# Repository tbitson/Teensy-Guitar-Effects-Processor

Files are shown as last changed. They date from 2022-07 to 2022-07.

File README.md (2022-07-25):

Teensy Guitar Effects Processor

This is an in-work project!

The Teensy Guitar Effects Processor (Teensy GEP or just GEP) is a microcontroller based sound effects processor designed for enhancing and modifying electric guitar sounds. It uses a Teensy microcontroller paired with a dedicated sound processing chip to provide a multitude of effects. 

The base design uses a Teensy 3.2 along with the Teensy Audio Shield from PJRC (pjrc.com) to process stereo audio at a full 16-bit 44.1kHz sample rate. The audio shield supports line-level-in, line-level out, and has an on-board headphone jack. The shield also contain a micro-SD card slot to allow recording and playback of sound. A separate battery powered pre-amp module interfaces most common electric guitar pickups to the line-level input. 

The design inspiration for the Teensy GEP is based on a project that appeared in the July 2017 edition of Circuit Cellar magazine by Brian Miller.  The original version of the source code (dubbed 1.0) does not seem to have any significant change since the article was published, and no longer compiles with the current version of the Teensy compiler and/or audio libraries. Significant changes to the baseline code were required to a) bring up-to-date with current library versions, 2) match the current compiler versions, and 3) to simplify the code so that my limited brain power could understand how the code worked (or at least how I thought I worked). 

Starting with Version 1.4, the memory requirements exceeded the Teensy 3.2, and either a Teensy 3.5 or 3.6 must be used. The devices are pin-for-pin compatable, however the 3.5 and 3.6 are both physically long with additional pins. A re-spin of the PC board will include the new footprint. This project is NOT electrically compatible with Teensy 4.0, but the software is. Change the #define in hardware.h to select your device.

The next milestone is to create a class hierarchy for the effects to allow easy implementation of new effects and/or changes to existing effects.

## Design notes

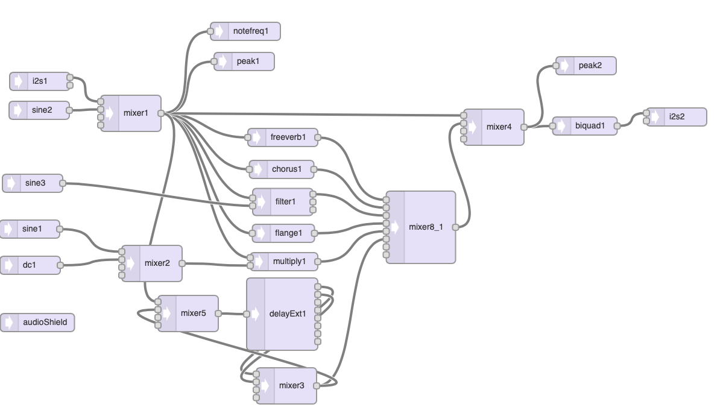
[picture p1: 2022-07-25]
Vers 185 Patches.png

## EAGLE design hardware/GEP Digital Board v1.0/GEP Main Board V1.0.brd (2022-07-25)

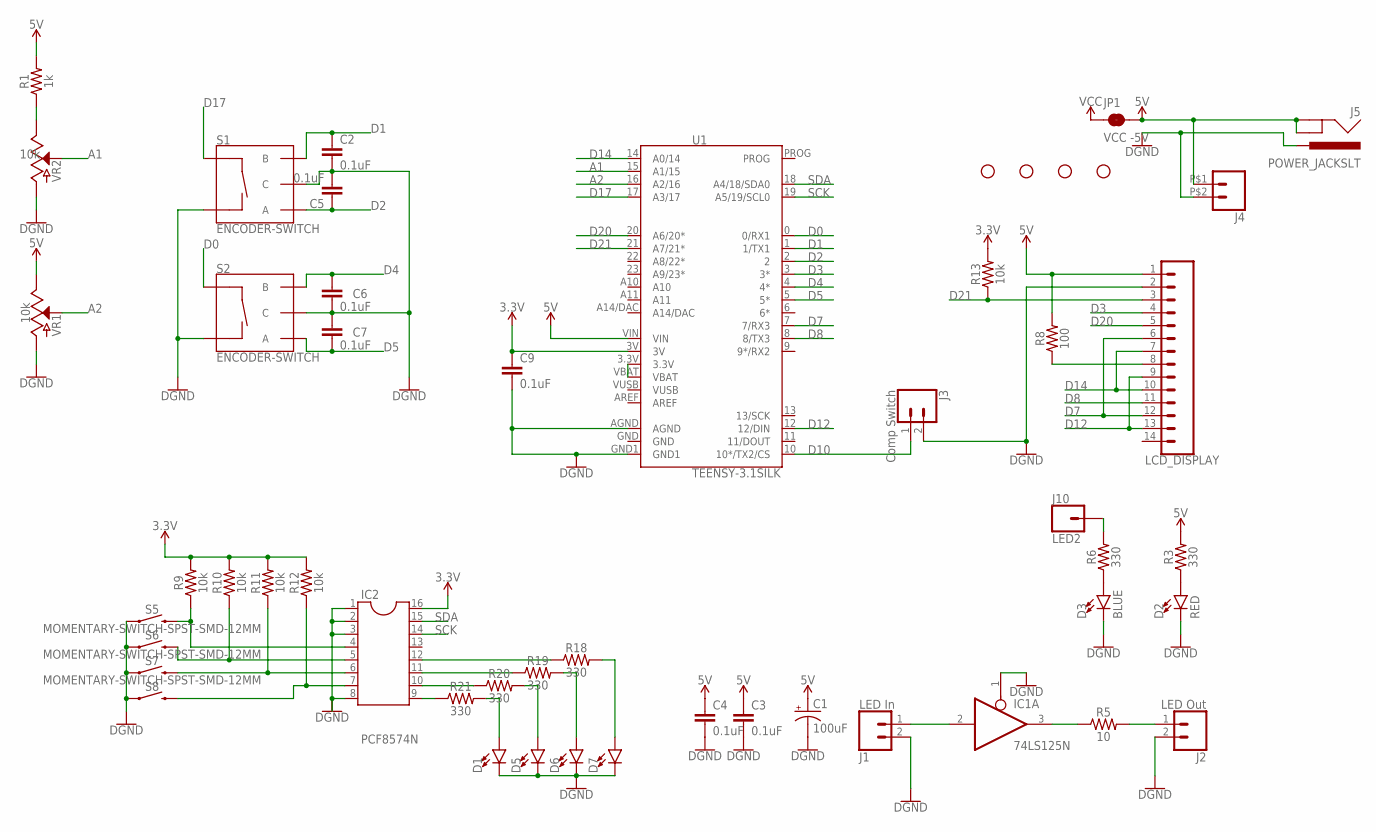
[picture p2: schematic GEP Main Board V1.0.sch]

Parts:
C1: 100uF; CPOL-RADIAL-2.5MM-6.5MM
C2, C3, C4, C5, C6, C7, C9: 0.1uF; CAP-PTH-SMALL-KIT
D1, D5, D6, D7: LED5MM; LED_5MM
D2: RED; LED_5MM
D3: BLUE; LED_5MM
H1, H2, H3, H4: STAND-OFF
IC1: 74LS125N; DIL14
IC2: PCF8574N; SOCKET-16
J1: LED In; 1X02
J2: LED Out; 1X02
J3: Comp Switch; 1X02
J4: CONN_02PTH2; 1X02_BIG
J5: POWER_JACKSLT; POWER_JACK_SLOT
J10: LED2; 1X01
JP1: VCC -5V; SMT-JUMPER_2_NC_TRACE_SILK
LCDDISPLAY: LCD_DISPLAY; 1X14
R1: 1k; AXIAL-0.3
R3, R6, R18, R19, R20, R21: 330; AXIAL-0.3
R5: 10; AXIAL-0.3
R8: 100; AXIAL-0.3
R9, R10, R11, R12, R13: 10k; AXIAL-0.3
S1, S2: ENCODER-SWITCH; ROTARY_ENC_PLAIN
S5, S6, S7, S8: MOMENTARY-SWITCH-SPST-SMD-12MM; TACTILE_SWITCH_SMD_12MM
U1: TEENSY-3.1SILK; TEENSY-3.1
VR1, VR2: 10k; POT-PTH-ALPS-KIT

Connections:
3.3V: C9.1, IC2.16, R9.P$2 (2), R10.P$2 (2), R11.P$2 (2), R12.P$2 (2), R13.P$2 (2), U1.3V
5V: C1.1 (+), C3.1, C4.1, J4.P$1 (1), J5.GND@1 (GNDBREAK), J5.GND@2 (GND), JP1.2, LCDDISPLAY.1, R1.P$2 (2), R3.P$2 (2), R8.P$2 (2), U1.VIN, VR1.P$1 (E)
A1: U1.15 (A1/15), VR2.P$2 (S)
A2: U1.16 (A2/16), VR1.P$2 (S)
D0: S2.SW+, U1.0 (0/RX1)
D1: C2.1, S1.B, U1.1 (1/TX1)
D2: C5.1, S1.A, U1.2
D3: LCDDISPLAY.4, U1.3 (3*)
D4: C6.1, S2.B, U1.4 (4*)
D5: C7.2, S2.A, U1.5 (5*)
D7: LCDDISPLAY.6, LCDDISPLAY.12, U1.7 (7/RX3)
D8: LCDDISPLAY.11, U1.8 (8/TX3)
D10: J3.1, U1.10 (10*/TX2/CS)
D12: LCDDISPLAY.9, LCDDISPLAY.13, U1.12 (12/DIN)
D14: LCDDISPLAY.7, LCDDISPLAY.10, U1.14 (A0/14)
D17: S1.SW+, U1.17 (A3/17)
D20: LCDDISPLAY.5, U1.20 (A6/20*)
D21: LCDDISPLAY.3, R13.P$1 (1), U1.21 (A7/21*)
GND: C1.2 (-), C2.2, C3.2, C4.2, C5.2, C6.2, C7.1, C9.2, D1.K (C), D2.K (C), D3.K (C), D5.K (C), D6.K (C), D7.K (C), IC1.1 (OE), IC1.7 (GND), IC2.1, IC2.2, IC2.3, IC2.8, J1.2, J2.2, J3.2, J4.P$2 (2), J5.PWR, LCDDISPLAY.2, S1.C, S1.SW-, S2.C, S2.SW-, S5.1, S6.1, S7.1, S8.1, U1.AGND, U1.GND, U1.GND1, VR1.P$3 (A), VR2.P$3 (A)
LED: LCDDISPLAY.8, R8.P$1 (1)
unnamed: U1.3.3V, U1.VBAT
unnamed: IC2.9, R21.P$1 (1)
unnamed: IC2.10, R20.P$1 (1)
unnamed: IC1.2 (I), J1.1
unnamed: IC1.3 (O), R5.P$1 (1)
unnamed: R1.P$1 (1), VR2.P$1 (E)
unnamed: D3.A, R6.P$1 (1)
unnamed: D2.A, R3.P$1 (1)
unnamed: IC2.5, R10.P$1 (1), S6.3 (2)
unnamed: IC2.6, R11.P$1 (1), S7.3 (2)
unnamed: IC2.7, R12.P$1 (1), S8.3 (2)
unnamed: IC2.4, R9.P$1 (1), S5.3 (2)
unnamed: J2.1, R5.P$2 (2)
unnamed: IC2.11, R19.P$1 (1)
unnamed: IC2.12, R18.P$1 (1)
unnamed: D1.A, R21.P$2 (2)
unnamed: D5.A, R20.P$2 (2)
unnamed: D6.A, R19.P$2 (2)
unnamed: D7.A, R18.P$2 (2)
unnamed: J10.1, R6.P$2 (2)
SCK: IC2.14, U1.19 (A5/19/SCL0)
SDA: IC2.15, U1.18 (A4/18/SDA0)
VCC: IC1.14 (VCC), JP1.1
VUSB: U1.VUSB

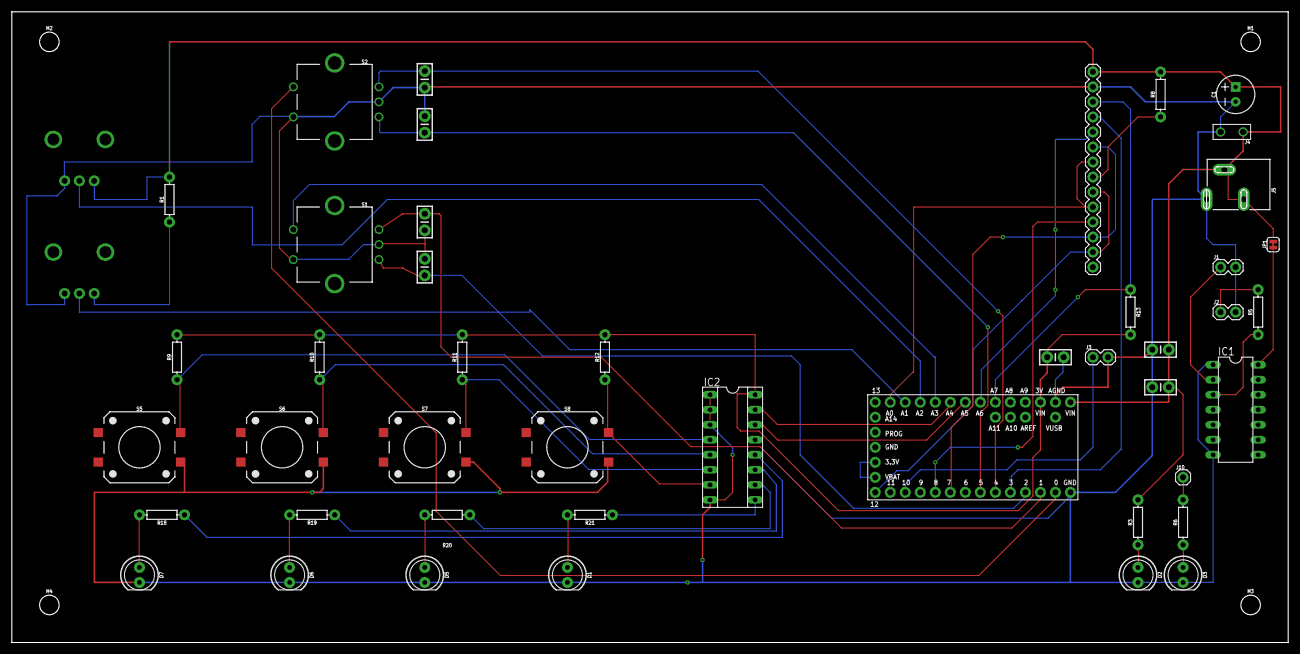
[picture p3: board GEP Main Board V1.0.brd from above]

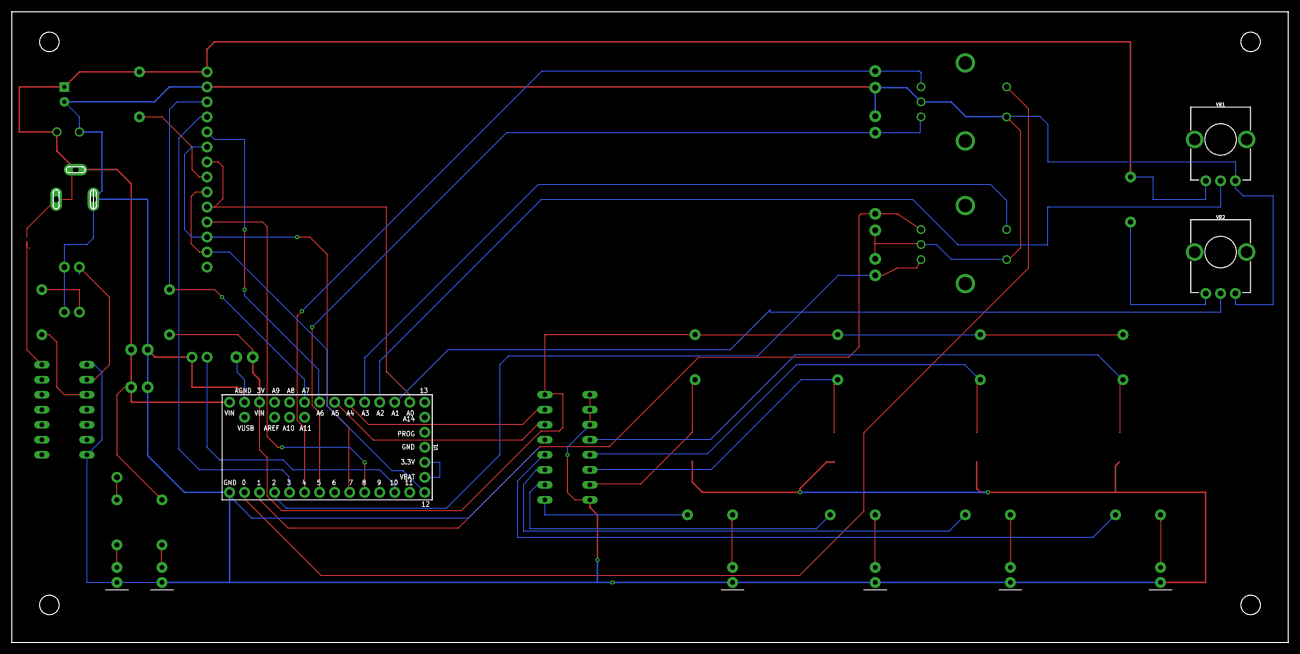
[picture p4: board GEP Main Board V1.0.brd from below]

Board: 2 copper layers, 215.9 x 106.7 mm, 51 parts (3 on the bottom side), 43 nets.

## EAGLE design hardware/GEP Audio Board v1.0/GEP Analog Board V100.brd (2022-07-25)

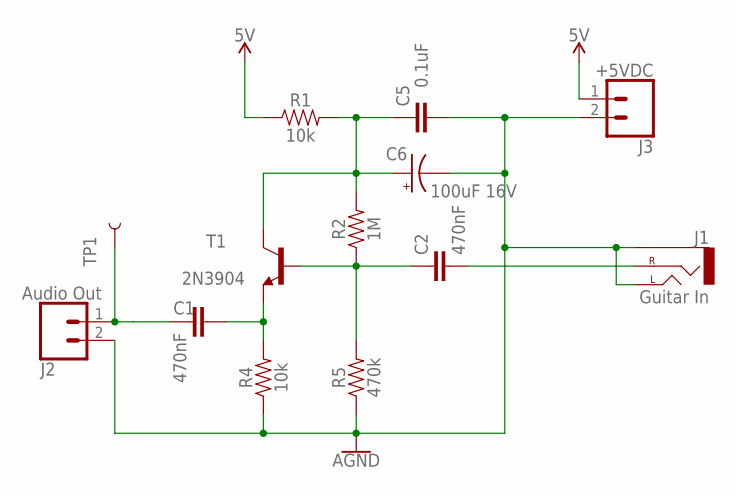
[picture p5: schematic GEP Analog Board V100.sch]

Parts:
C1, C2: 470nF; CAP-PTH-SMALL-KIT
C5: 0.1uF; CAP-PTH-SMALL-KIT
C6: 100uF 16V; CPOL-RADIAL-2.5MM-6.5MM
J1: Guitar In; STEREOJACK2.5MM_SPECIAL_POGOPINS
J2: Audio Out; 1X02
J3: +5VDC; 1X02
R1, R4: 10k; AXIAL-0.3
R2: 1M; AXIAL-0.3
R5: 470k; AXIAL-0.3
T1: 2N3904; TO92
TP1: TEST-POINTTP_15TH_THRU; TP_15TH

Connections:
5V: J3.1, R1.P$1 (1)
AGND: C5.2, C6.2 (-), J1.RING1 (SLEEVE), J1.SHIELD (LEFT), J2.2, J3.2, R4.P$1 (1), R5.P$1 (1)
unnamed: C2.1, R2.P$1 (1), R5.P$2 (2), T1.2 (B)
unnamed: C2.2, J1.TIP (RIGHT)
unnamed: C1.2, J2.1, TP1.P$1
unnamed: C1.1, R4.P$2 (2), T1.3 (E)
unnamed: C5.1, C6.1 (+), R1.P$2 (2), R2.P$2 (2), T1.1 (C)

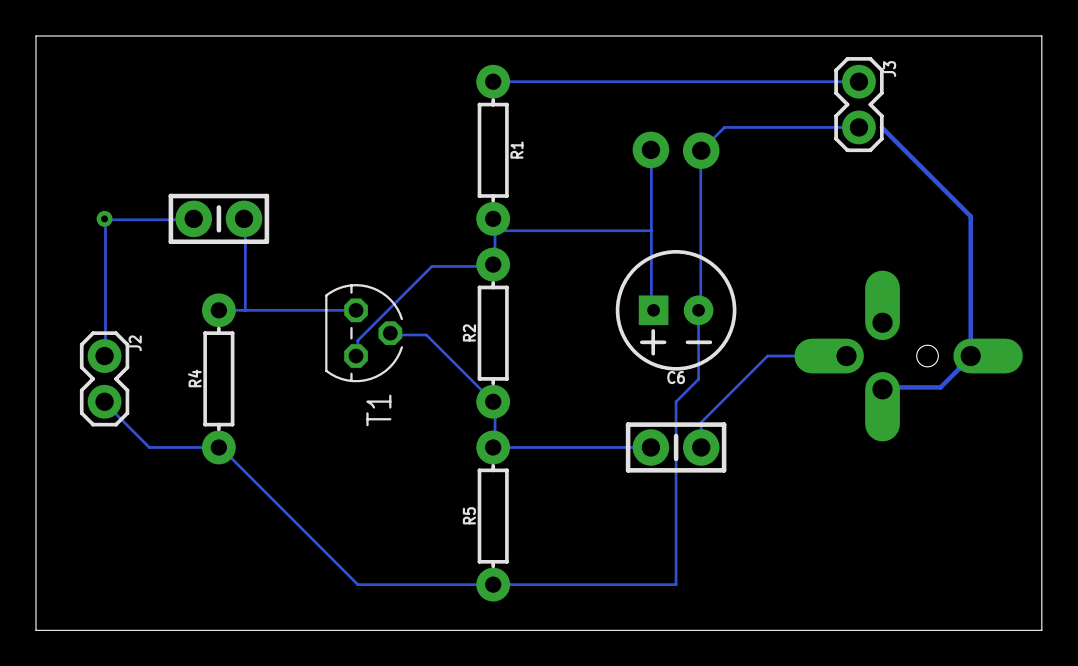
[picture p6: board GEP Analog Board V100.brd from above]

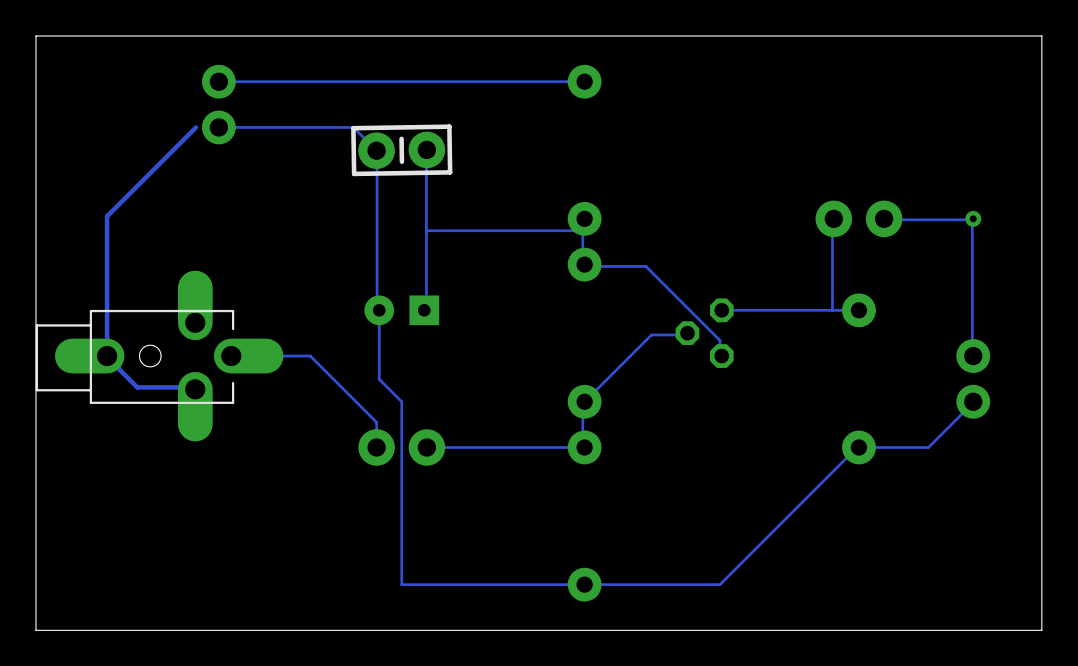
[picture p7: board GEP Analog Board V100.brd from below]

Board: 2 copper layers, 55.9 x 33.0 mm, 13 parts (2 on the bottom side), 7 nets.

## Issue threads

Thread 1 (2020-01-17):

Conflict on SPI bus between Teensy Audio Board and LCD

tbitson, 2020-01-17:
Conflict on SPI Bus (?) causes lcd to wig out sometimes
- goes blank, turns white, or freezes
 - requires power cycle to clear.

One option is to use Teensy 3.5/3.6 SPI2 port, but would require routing wire around PC board or drilling (until respin)

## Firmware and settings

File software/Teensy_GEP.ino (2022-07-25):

/***************************************************************************
    Teensy Guitar Effects Processor (GEP)

    This version only works with Teensy 3.5 or 3.6
    Build settings: CPU '120 MHz', USB Type 'Serial',  Optimize 'Fast woth LTO',

    Version 1.8.5  09Sept2020

    Repository: https://github.com/tbitson/Teensy-Guitar-Effects-Processor

    Arduino version used: 1.8.12
    Teensyduino version used: 1.48

    Based on Teensy Digital Guitar Amplifier / Effects Processor
    by Brian Miller Circuit Cellar July 2017

    Version 1.3 updated original project to current versions of
    the audio library, Arduino, and Teensyduino

    Version 1.4 switched to the 'freeverb' reverb engine, which
    exceeded Teensy 3.2 memory capability, so switched to teensy 3.5/3.6

    Version 1.5 was a complete organization change, some gui code rewritten,
    added multi-delay effect and screen, converted config to struct. This
    is the beginning of a conversion to use classes for the effects to make
    it a bit easier to add new effects. Never Released.

    Version 1.6 - bug fixes and clean-up to version 1.5.
    Shortened name to Teensy_GEP. Issue with TFT LCD and Audio Sheild sharing
    SPI bus. Temp workaround is to add delays at startup. Added test tone
    at the input to check effect without an audio source. Required an additional
    mixer at input. Holding down tuner button sets a dev mode that allows changes to
    behavior without affecting normal operation. Use to enable test tone using wahwah
    button. Enabled headphones output in addion to line out, need provision
    to adjust level. Added line out level indicator in input screen. Added 4 channel
    delay and screen. Added detection of a long press on effects buttons to allow
    toggling of 8 effects, no led indicators though. Selecting an effect also
    switches screens to the effect chosen. Reverb is now downstream of the other
    effects, which required a new mixer and logic changes. Guitar tuner changes seems
    to be working pretty good when compared to a commercial product. Test led is now
    toggled in the main loop, indicating we're alive. Maybe repurpose power led?
    Added serial interface. Enter '?' in terminal to see menu. Allows control via
    USB and monitoring mem usage, effects status, etc. Very helpful when creating
    new effects; no gui needed. Only a few commands so far.

    Version 1.7 - completed conversion of effects to classes. Ain't as clean as
    I hoped, still some room to optimize. Some major re-arrangement of code. Moved
    hardware related functions from main to hardware.h. Created radio button group
    in guiItems.h to handle the buttons in Compressor.h. Test tone is now injected
    at the beginning of the audio chain, not just in the dry path. Added status
    screen to provide a quick visual of effects status. Disabled audio interrupts
    at startup to minimize the 'clunk' when initializing the audio board. Delay
    changed to 2 channels, but added a feedback or 'reciculate' options with
    a slider. Added a status screen to show which effects are enabled; touch the
    center of the LCD. Expanded the serial command to allow enabling or disabling
    of all effects, added screem selection, etc.

    Version  1.8 - Added an 8-channel mixer to the GUI tools and Teensy Audio Lib.
    Converted code to use the 8-channel mixer which eliminated 2 4-channel mixers,
    thereby simplifing things a little. Added a lowpass "cab filter" to output to
    mellow the tone. Added output wet/dry mixer. Patched AVC code in audio lib.


    known bugs & todo:
    1) Hang on boot: seems to be a conflict between LCD and audio board serial flash that
    causes an intermittant hang on boot. Startup sequence rearranged, seems better but not fixed.
    2) Compressor - bug in teensy audio lib, see pull #210, manually applied
    3) High freq noise under some condtions - seems to be coupled through USB
    todo: decide if current values are kept in cfg.xxx or in the class (probably class)
    i.e. the config code is now somewhat dated.
    todo: test compressor now that bug in lib is patched.
    todo: re-do the guiItems now that they mostly work
    todo: add indicator when bypass switch is in bypass
    todo: consider ditching the mix pot; since each effect has it's own volume
          control (usally a mixer channel), its redundant. Set each effect on its own.
    todo: move slider code from each effect into guiItems.h
    todo: refactor guiItems.h to move lcd code into a new file 



 ********************************************************************************/


const String VERSION = "Vers. 1.8.5";


// set to enable helpful diagnostic print-outs
bool debugPrint = true;

// allow serial port commands
#define USE_SERIAL_CMDS

// go to status screen after 30 seconds
//#define STATUS_SCREEN_ON_TIMEOUT

// jump to setting when effects selected
//#define SHOW_EFFECTS_SETTINGS


// audio patchpanel from audio tool
#include "patches.h"


// program includes
#include "utils.h"      // print routines, misc stuff
#include "config.h"     // default settings & eeprom storage
#include "hardware.h"   // hardware connections


// prototypes
void adjustMixValue();
void adjustWahWahValue();
void startGuitarTuner();
void playTone();
void printConfig();
void printStatus();
void doSerialCommands();



// add all the effects
#include "Compressor.h"
#include "EQ.h"
#include "Reverb.h"
#include "Delayer.h"
#include "Flanger.h"
#include "Tremolo.h"
#include "WahWah.h"
#include "Chorus.h"
#include "Levels.h"


// create instances of effects
Compressor compressor;
EQ  eq;
Delayer delayer;
Reverb reverb;
Tremolo tremolo;
Flanger flanger;
WahWah wahwah;
Chorus chorus;
Levels levels;

// include after declaring classes
#include "status.h"     // status screen
#include "tuner.h"
#include "update.h"



// number of menus
#define NUM_MENUS       8

// order of effect screens
#define EQ_SCREEN          0
#define COMPRESSOR_SCREEN  1
#define TREMOLO_SCREEN     2
#define REVERB_SCREEN      3
#define FLANGER_SCREEN     4
#define DELAY_SCREEN       5
#define CHORUS_SCREEN      6
#define INPUT_SCREEN       7
#define STATUS_SCREEN      8



// menu vars
uint8_t menuIndex = 0;
uint8_t lastMenuIndex = 0;
uint32_t menuChangedTime = 0;
boolean initScreen = true;
boolean msgFlag = false;
uint8_t tunerMode = 0;

// button timer
uint32_t lastTime;

// pot values
int mixPot;
int wahWahPot;





// *** start processing ***


void setup()
{
  // start serial port
  Serial.begin(57600);

  // configure hardware i/o pins
  pinMode(TUNER_SWITCH_PIN, INPUT_PULLUP);
  pinMode(SAVE_SWITCH_PIN, INPUT_PULLUP);
  pinMode(TEST_LED, OUTPUT);

  // turn on led to show we're awake
  digitalWrite(TEST_LED, ON);
  
  // wait for cpu & lcd to initialize
  delay(1000);

  // what teensy are we using?
  checkTeensyType();

  Serial.print("Teensy GEP "); 
  Serial.println(VERSION);
  Serial.println(procType);

  // start eeprom library
  EEPROM.begin();

  // check for tuner button down, if so, we'll reset to default config
  if (digitalRead(TUNER_SWITCH_PIN) == 0)
  {
    Serial.println("resetting to defaults");
    // bypass loading eeprom config
    loadDefaults();

    // blink led to show reset
    blinkLED(3);
  }
  else
  {
    // load configuration
    loadConfig();
  }


  printValue("Configuring Audio...");

  // allocate memory for audio (mostly for delays)
  AudioMemory(256);

  // Enable the audio shield and set the output volumes
  printValue("Enabling audio module");
  audioShield.enable();                              // start audio board
  delay(100);

  audioShield.muteHeadphone();
  audioShield.muteLineout();
  audioShield.inputSelect(AUDIO_INPUT_LINEIN);    // use the line-in input
  audioShield.volume(HEADPHONE_OUTPUT_LEVEL);     // headphone output level
  audioShield.lineOutLevel(LINEOUT_AUDIO_LEVEL);  // 3.16 V p-p out
  audioShield.audioPostProcessorEnable();         // enable SGTL5000 effects processing
  //audioShield.adcHighPassFilterDisable();       // Turn off ADC HP filter (Forum claims this reduces audio noise)

  // set up cab filter 2-stages of LPF, cutoff 4500 Hz, Q-factor 0.7071
  biquad1.setLowpass(0, 4500, .7071);
  biquad1.setLowpass(1, 4500, .7071);


  printValue("Initialzing Effects");
  compressor.init();
  eq.init();
  reverb.init();
  delayer.init();
  tremolo.init();
  flanger.init();
  wahwah.init();
  chorus.init();
  levels.init();

  // configure a sine wave for the test tone and disable
  sine2.frequency(500);   // 500 Hz
  sine2.amplitude(0.5);   // 50% amplitude

  // initialize encoders
  paramEncoder.write(0);
  valueEncoder.write(0);

  // init leds & pushbutton interface IC
  PCF.write8(0xff);

  // flush serial port recieve buffer
  while (Serial.available() > 0)
  {
    char c = Serial.read();
    Serial.print(c);
  }


  // update all global audio settings
  updateMix(readMixPot());
  updateWahWah(readWahWahPot());
  updateAudio();

  // fire up the lcd screen
  initLCD();
  delay(1000);

  // show the splash screen
  splashScreen();
  delay(4000);

  // recall last menu used
  menuIndex = cfg.lastMenu;

  // let everyting settle
  delay(500);

  printValue("Enabling Touchscreen");
  ts.begin();
  
  // ok, here we go...
  delay(500);
  audioShield.unmuteHeadphone();
  audioShield.unmuteLineout();

  Serial.println("Setup complete");
}




// *** main loop ***

void loop()
{
  uint8_t switchPressed;
  String message;

  // slow loop down just a bit
  delay(50);

  // blink test led to show we're alive
  if (millis() - lastTime > 1000)
  {
    digitalWrite(TEST_LED, !digitalRead(TEST_LED));
    lastTime = millis();
  }

  // save switch pressed ?
  saveSwitch.update();
  if (saveSwitch.fallingEdge())
  {
    printValue("Save Button Pressed");
    saveConfig();
    message = "Config Saved";
    msgFlag = true;
  }

  // tuner switch pressed ?
  tunerSwitch.update();
  if (tunerSwitch.fallingEdge())
  {
    if (debugPrint) Serial.println("Tuner Button Presssed");
    startGuitarTuner();
  }


  // read front panel pots
  mixPot = readMixPot();
  if (abs(mixPot - lastMixPot) > 3)
    updateMix(mixPot);


  // read wah-wah pot
  wahWahPot = readWahWahPot();
  if (abs(wahWahPot - lastWahWahPot) > 3)
    updateWahWah(wahWahPot);


  // Read the front panel buttons
  switchPressed = readButtons();
  if (switchPressed)
  {
    switch (switchPressed)
    {
      case 0x01:  // Reverb switch
        printValue("Toggle Reverb");
        reverb.toggle();
        message = reverb.enabled ? "Reverb ON" : "Reverb OFF";
        msgFlag = true;
        menuIndex = REVERB_SCREEN;
        break;

      case 0x02:  // Flanger Switch
        printValue("Toggle Flanger");
        flanger.toggle();
        message = flanger.enabled ? "Flanger ON" : "Flanger OFF";
        msgFlag = true;
        menuIndex = FLANGER_SCREEN;
        break;

      case 0x04:  // Tremolo switch
        printValue("Toggle Tremolo");
        tremolo.toggle();
        message = tremolo.enabled ? "Tremolo ON" : "Tremolo OFF";
        msgFlag = true;
        menuIndex = TREMOLO_SCREEN;
        break;

      case 0x08:  // Wah-Wah switch
        printValue("Toggle Wah-Wah");
        wahwah.toggle();
        message = wahwah.enabled ? "Wah-Wah ON" : "Wah-Wah OFF";
        msgFlag = true;
        break;

      case 0x81:
        delayer.toggle();
        message = delayer.enabled ? "Delay ON" : "Delay OFF";
        msgFlag = true;
        menuIndex = DELAY_SCREEN;
        break;

      case 0x82:
        chorus.toggle();
        message = chorus.enabled ? "Chorus ON" : "Chorus OFF";
        msgFlag = true;
        menuIndex = CHORUS_SCREEN;
        break;

      case 0x84:
        eq.toggle();
        message = eq.enabled ? "EQ ON" : "EQ OFF";
        msgFlag = true;
        menuIndex = EQ_SCREEN;
        break;

      case 0x88:
        compressor.toggle();
        message = compressor.enabled ? "Compressor ON" : "Compressor OFF";
        msgFlag = true;
        menuIndex = COMPRESSOR_SCREEN;
        break;

      default:
        message = "Hmm.... Inavlid Button!!";
        msgFlag = true;
        break;
    }
    updateLEDs();
  }


  // screen update loop  - continously call the current screen
  if (menuIndex != lastMenuIndex)
  {
    printValue("menuIndex", menuIndex);
    initScreen = true;
    resetEncoders();
    menuChangedTime = millis();
    lastMenuIndex = menuIndex;
  }

  switch (menuIndex)
  {
    case EQ_SCREEN:
      eq.process(initScreen);
      break;

    case COMPRESSOR_SCREEN:
      compressor.process(initScreen);
      break;

    case TREMOLO_SCREEN:
      tremolo.process(initScreen);
      break;

    case FLANGER_SCREEN:
      flanger.process(initScreen);
      break;

    case REVERB_SCREEN:
      reverb.process(initScreen);
      break;

    case INPUT_SCREEN:
      levels.process(initScreen);
      break;

    case DELAY_SCREEN:
      delayer.process(initScreen);
      break;

    case CHORUS_SCREEN:
      chorus.process(initScreen);
      break;

    case STATUS_SCREEN:
      statusScreen(initScreen);
      break;

    default:
      printValue("Error: Invalid Screen Selection", menuIndex);
  }

  initScreen = false;


  // check touchscreen
  if (ts.touched())
  {
    TS_Point p = ts.getPoint();
    printPoint(p);

    // touched left half - previous menu
    if (p.x < 1200)
    {
      if (menuIndex > 0)
        menuIndex--;
      else
        menuIndex = NUM_MENUS - 1;
    }

    // touched right half - next menu
    else if (p.x > 2800)
    {
      menuIndex++;
      if (menuIndex > NUM_MENUS - 1)
        menuIndex = 0;
    }

    // touched center - go to status screen
    else
      menuIndex = STATUS_SCREEN;

    cfg.lastMenu = menuIndex;

    // add a delay after touch detected
    delay(100);
  }


  // is there a message to display?
  if (msgFlag)
  {
    tftMessage(message);
    msgFlag = false;
    // redraw last screen
    initScreen = true;
  }


  // is there a serial command waiting?
  doSerialCommands();


#ifdef STATUS_SCREEN_ON_TIMEOUT
  // time to go back to status screen?
  if (menuIndex != STATUS_SCREEN)
  {
    if (millis() - menuChangedTime > 60000)
    {
      menuIndex = STATUS_SCREEN;
      menuChangedTime = millis();
    }
  }
#endif
}



void updateLEDs()
{
  setLED(REVERB_LED,  reverb.getStatus());
  setLED(FLANGER_LED, flanger.getStatus());
  setLED(TREMOLO_LED, tremolo.getStatus());
  setLED(WAH_WAH_LED, wahwah.getStatus());
}



void printPoint(TS_Point p)
{
  Serial.print("Pressure = "); Serial.println(p.z);
  Serial.print("Screen X = "); Serial.println(p.x);
  Serial.print("Screen Y = "); Serial.println(p.y);
  Serial.println();
}




void startGuitarTuner()
{
  // Disable all effects to minimize memory and cpu usage
  compressor.disable();
  flange1.voices(0, 0, 0);

  // enable inputs, not tone or delay feedback
  mixer1.gain(LEFT_IN, 1.0);
  mixer1.gain(TEST_TONE, 0);

  // turn off effects and enable dry
  mixer8_1.gain(REVERB_IN, 0);
  mixer8_1.gain(CHORUS_IN, 0);
  mixer8_1.gain(WAH_WAH_IN, 0);
  mixer8_1.gain(FLANGER_IN, 0);
  mixer8_1.gain(TREMOLO_IN, 0);
  mixer8_1.gain(DELAY_IN, 0);


  // launch the guitar tuner
  guitarTuner();

  // restart flanger
  flanger.init();

  // reset compressor
  if (cfg.compEnabled)
    compressor.enable();

  // read current pot settings
  mixPot = readMixPot();
  wahWahPot = readWahWahPot();

  // set audio controls back to current values
  updateMix(mixPot);
  updateWahWah(wahWahPot);
  updateAudio();

  // go to menu screen
  initScreen = true;
  menuIndex = cfg.lastMenu;
}



void playTone()
{
  // enable mixer channel & leave on for now
  printValue("Playing Tone");
  mixer1.gain(TEST_TONE, 1.0);
  delay(120);
  mixer1.gain(TEST_TONE, 0);
  printValue("done");
}



void playLongTone()
{
  // enable mixer channel & leave on for now
  printValue("Playing Tone");

  mixer1.gain(TEST_TONE, 1.0);

  // read pots and buttons while playing tone
  for (int j = 0; j < 50; j++)
  {
    loop();
    delay(100);
  }
  mixer1.gain(TEST_TONE, 0);
  printValue("done");
}




void doSerialCommands()
{
  // check for incoming data on serial port
  if (Serial.available())
  {
    // read 1st character, preserving the rest
    char c = Serial.read();

    // filter out non-printable characters
    if (c > 32 && c < 127)
    {
      Serial.print("Serial Cmd ->"); Serial.println(c);

      switch (c)
      {
        case 'p':
          printConfig();
          break;

        case 'm':
          printAudioMemUsage();
          break;

        case 's':
          printStatus();
          break;

        case 'M':
          menuIndex++;
          if (menuIndex > NUM_MENUS - 1 )
            menuIndex = 0;
          break;

        case 't':
          playTone();
          break;

        case 'l':
          playLongTone();
          break;

        case 'R':
          reverb.toggle();
          updateLEDs();
          break;

        case 'T':
          tremolo.toggle();
          updateLEDs();
          break;

        case 'F':
          flanger.toggle();
          updateLEDs();
          break;

        case 'W':
          wahwah.toggle();
          updateLEDs();
          break;

        case 'C':
          compressor.toggle();
          break;

        case 'E':
          eq.toggle();
          break;

        case 'D':
          delayer.toggle();
          break;

        case 'c':
          chorus.toggle();
          break;

        case 'd':
          // toggle delay recirculate
          if (delayer.getRecirculate() > 0)
            delayer.setRecirculate(0);
          else
            delayer.setRecirculate(0.4);
          delayer.process(true);
          break;

        case '!':
          reverb.disable();
          flanger.disable();
          tremolo.disable();
          wahwah.disable();
          delayer.disable();
          compressor.disable();
          chorus.disable();
          eq.disable();
          break;

        case '$':
          clearEEPROM();
          break;

        case '?':
          Serial.println(F("p: Print config"));
          Serial.println(F("m: print Memory usage"));
          Serial.println(F("s: print effects Status"));
          Serial.println(F("t: play test Tone"));
          Serial.println(F("l: play long test Tone"));
          Serial.println(F("M: Move to next screen"));

          Serial.println(F("C: toggle Compressor"));
          Serial.println(F("E: toggle Equalizer"));
          Serial.println(F("R: toggle Reverb"));
          Serial.println(F("F: toggle Flanger"));
          Serial.println(F("T: toggle Tremolo"));
          Serial.println(F("W: toggle WahWah"));
          Serial.println(F("D: toggle Delayer"));
          Serial.println(F("c: toggle Chorus"));

          Serial.println(F("d: toggle Delay Recirculate"));

          Serial.println(F("!: Reset All Effects"));
          Serial.println(F("$: Clear EEPROM"));

          Serial.println(F("?: print help"));
          Serial.println();
          break;

        default:
          Serial.println(F("I'm sorry Dave, I afraid I can't do that"));
      }
    }
  }
}




void printConfig()
{
  Serial.println();
  Serial.println(F("Current Config:"));
  Serial.print(F("Version = ")); Serial.println(cfg.vers);

  compressor.printConfig();
  eq.printConfig();
  reverb.printConfig();
  tremolo.printConfig();
  delayer.printConfig();
  flanger.printConfig();
  levels.printConfig();
  chorus.printConfig();
  wahwah.printConfig();

  Serial.print(F("Last Menu  = ")); Serial.println(cfg.lastMenu);
  Serial.println();
  delay(200);
}



void printStatus()
{
  Serial.print(F("Compressor enabled = ")); Serial.println(compressor.getStatus());
  Serial.print(F("EQ enabled         = ")); Serial.println(eq.getStatus());
  Serial.print(F("Reverb enabled     = ")); Serial.println(reverb.getStatus());
  Serial.print(F("Flanger enabled    = ")); Serial.println(flanger.getStatus());
  Serial.print(F("Delay enabled      = ")); Serial.println(delayer.getStatus());
  Serial.print(F("Tremolo enabled    = ")); Serial.println(tremolo.getStatus());
  Serial.print(F("Chorus enabled     = ")); Serial.println(chorus.getStatus());
  Serial.print(F("Wah-Wah enabled    = ")); Serial.println(wahwah.getStatus());
}

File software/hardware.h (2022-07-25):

/*******************************************************************************
   hardware.h -  Hardware definitions and functions

   Version 1.3   Jan 2020

   Pin definitions and initialization routines for:
        TFT LCD Display
        Rotory Encoders
        Analog Pots
        on-board switches (save & tuner)
        external switch (TBD)
        Test LED
        PCF8574 i2c bus expander controlling
           4 indicator leds
           4 pushbutton switches



   reference: pins used by audio shield
   audio data:     9, 11, 13, 22, 23
   audio control: 18, 19          (I2C)
   volume pot:    15              (A1)
   sd card:        7, 10, 12, 14  (SPI)
   ext sram:       6,  7, 12, 14  (SPI)

   SPI used for external delay. With current design,
   pins 7, 12, and 14 are shared with TFT LCD, which
   seems to cause problems getting the LCD started

    Pin  Signal
     6  CS
     7  MOSI
    12  MISO
    14  SCK

*******************************************************************************/



#ifndef HARDWARE_H
#define HARDWARE_H




// hardware libraries
#include <Encoder.h>
#include <Bounce.h>
#include <PCF8574.h>
#include <ILI9341_t3.h>
#include <XPT2046_Touchscreen.h>

#include "guiItems.h"


// prototypes
void checkTeensyType();
void resetEncoders();
long readParamEncoder();
long readValueEncoder();
int readMixPot();
int readWahWahPot();
uint8_t readButtons();
void setLED(uint8_t led, bool state);
void blinkLed(uint8_t blinks);


// global vars for encoder & pot status values
long paramEncVal;
long lastParamEncVal;
long valEncVal;
long lastValEncVal;
String procType = "UNKNOWN";

// previous pot values
int lastMixPot = 0;
int lastWahWahPot = 0;

// uncomment to use the SD Card
//#define USE_SD_CARD


// simple defines
#define OFF 0
#define ON  1
#define UNITY_GAIN  1.0
#define GAIN_UNITY  1.0
#define GAIN_OFF    0



// TFT LCD SPI pins (255 = always on)
#define TFT_DC   20
#define TFT_CS   21
#define TFT_RST  255
#define TFT_MOSI 7
#define TFT_SCLK 14
#define TFT_MISO 12

// touchscreen chip select line
#define CS_PIN  8



// Use these with the Teensy 3.5/3.6 built-in SD card
#ifdef USE_SD_CARD
#ifdef TEENSY_35
#define SDCARD_CS_PIN    BUILTIN_SDCARD
#define SDCARD_MOSI_PIN  11
#define SDCARD_SCK_PIN   13
#endif
#ifdef TEENSY_36
#define SDCARD_CS_PIN    BUILTIN_SDCARD
#define SDCARD_MOSI_PIN  11
#define SDCARD_SCK_PIN   13
#endif
#ifdef TEENSY_32
// use the sd card on the Teensy Audio Shield
#define SDCARD_CS_PIN    10
#define SDCARD_MOSI_PIN  7
#define SDCARD_SCK_PIN   14
#endif
#endif


// activity led pin, use additional pin on 3.5/3.6
#ifdef TEENSY_32
#define TEST_LED    3
#else
#define TEST_LED    24
#endif



// rotary encoder pins
#define ENCODER1_PIN1   1
#define ENCODER1_PIN2   2
#define ENCODER2_PIN1   4
#define ENCODER2_PIN2   5


// on-board potentiometers - could be pedal inputs
#define WAH_WAH_POT   A1
#define MIX_POT       A2

// on-board switches (pressing the encoder button)
#define TUNER_SWITCH_PIN        0
#define SAVE_SWITCH_PIN         17


// external switch - depricated
// #define EXTERNAL_SWITCH_PIN   10

// Switch Debounce Time
#define DEBOUNCE_MS    15

// PCF8574 Remote 8-Bit I/O Expander for I2C Bus
// Interface to the LED and Buttson
#define PCF8574_ADDRESS  0x20

// PCF8574 LEDs
// leds inverted
#define LED_ON          0
#define LED_OFF         1

// PCF8574 Switch defines
// buttons inverted
#define SWITCH_ON       0
#define SWITCH_OFF      1

// PCF8574 LED numbers
#define REVERB_LED      7
#define FLANGER_LED     6
#define TREMOLO_LED     5
#define WAH_WAH_LED     4

// PCF8574 button numbers
#define REVERB_SWITCH   0
#define FLANGER_SWITCH  1
#define TREMOLO_SWITCH  2
#define WAH_WAH_SWITCH  3

// future and in-work stuff
//#define BYPASS_LED    39

// cable notes
// BLK - GND
// BRN - BYPASS_SWITCH (active low)
// RED - A21
// ORG - RIGHT_CH_OUT
// YEL - RIGHT_CH_IN
// GRN - A22
// BLU - LEFT_CH_IN
// VIO - LEFT_CH_OUT



/*************************************************/


// *** create hardware instances ***

// create TFT LCD Display
ILI9341_t3 tft = ILI9341_t3(TFT_CS, TFT_DC, TFT_RST, TFT_MOSI, TFT_SCLK, TFT_MISO);

// create instance of touchscreen - non-interrupt config
XPT2046_Touchscreen ts(CS_PIN);

// create instances of rotory encoders
Encoder valueEncoder(ENCODER1_PIN1, ENCODER1_PIN2);
Encoder paramEncoder(ENCODER2_PIN1, ENCODER2_PIN2);

// create instances to switch debouncers
Bounce tunerSwitch = Bounce(TUNER_SWITCH_PIN, DEBOUNCE_MS);
Bounce saveSwitch  = Bounce(SAVE_SWITCH_PIN, DEBOUNCE_MS);

// create instance of I2C Expansion chip for LEDs & Switches
PCF8574 PCF(PCF8574_ADDRESS);





void checkTeensyType()
{
  // which teensy are we using?
#ifdef __MK20DX256__
#define TEENSY_32
  Serial.println( "Teensy 3.2");
  procType = "Teensy 3.2";

#elif defined(__MK64FX512__)
#define TEENSY_35
  Serial.println( "Teensy 3.5");
  procType = "Teensy 3.5";
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

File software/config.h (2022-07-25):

/******************************************************
   config.h

   Global settings, variables, and functions to
   save and load to non-volatile memory (EEPROM).
   Set the default values if EEPROM contents do
   not match the current version.

   version 1.2   Jan 2020


 ********************************************************/

#ifndef CONFIG_H
#define CONFIG_H


#include <EEPROM.h>



// prototypes
void loadDefaults();
bool saveConfig();
bool loadConfig();
void clearEEPROM();
void showEEPROM();



// if the first byte of stored data matches this, it
// is assumed valid data for this version
#define EEPROM_VERSION 183
#define EEPROM_ADDR    0

// equalizer bands
#define NUM_EQ_BANDS  5
enum eqBands {BASS, MID_BASS, MIDRANGE, MID_TREBLE, TREBLE};

#define HEADPHONE_OUTPUT_LEVEL 0.7
#define LINEOUT_AUDIO_LEVEL    8


// dev mode - alters some buttons to execute debugging functions
// hold down Tuner button at startup to enter. Stuff that is altered
// changes depending on what's being debugged.
bool devMode = false;


// the settings saved to non-volatile memory
struct Config
{
  byte    vers;

  float   eqBandVals[5];
  int     updateFilter[5];

  bool    compEnabled;
  uint8_t compGain;
  uint8_t compResponse;
  uint8_t compLimit;
  float   compThreshold;
  float   compAttack;
  float   compDecay;

  float   tremoloVolume;
  float   tremoloSpeed;
  float   tremoloDepth;

  float   flangerSpeed;
  int16_t flangerDepth;

  float   reverbVolume;
  float   reverbRoomsize;
  float   reverbDamping;

  float   delayTimes[4];
  float   delayVols[4];
  float   recirculate;

  float   chorusVoices;
  float   chorusVolume;

  uint8_t inputLevel;

  uint8_t lastMenu;
};

// create instance of configuration struct
Config cfg;



void loadDefaults()
{
  // set up defaults
  cfg.vers                    = EEPROM_VERSION;

  // equalizer - set for flat response
  cfg.eqBandVals[BASS]        = 0.0;
  cfg.eqBandVals[MID_BASS]    = 0.0;
  cfg.eqBandVals[MIDRANGE]    = 0.0;
  cfg.eqBandVals[MID_TREBLE]  = 0.0;
  cfg.eqBandVals[TREBLE]      = 0.0;

  // compressor
  cfg.compEnabled   = false;
  cfg.compGain      = 1;       // 0 = 0db, 1 = 6db, 2 = 12db
  cfg.compResponse  = 1;       // integration time 0 = 0ms, 1 = 25ms, 2 = 50ms, 3 = 100ms
  cfg.compLimit     = 0;       // 0 = soft knee, 1 = hard limit, not in gui
  cfg.compThreshold = -20;     // 0 to -96dbBFS
  cfg.compAttack    = 3.0;     // db per sec
  cfg.compDecay     = 4.0;     // db per sec

  // tremolo
  cfg.tremoloVolume = 0.8;     // 0 to 1.0
  cfg.tremoloSpeed  = 3.0;     // 0.5 to 8.0 Hz
  cfg.tremoloDepth  = 0.4;     // 0 to 1.0

  // reverb
  cfg.reverbVolume   = 0.7;    // 0 to 1.0
  cfg.reverbRoomsize = 0.5;    // 0 to 1.0
  cfg.reverbDamping  = 0.3;    // 0 to 1.0

  // delayer
  cfg.delayTimes[0] = 200;     // delay in ms, 0 to 1000
  cfg.delayTimes[1] = 0;       // delay in ms, 0 to 1000
  cfg.delayVols[0]  = 0.8;     // delay chan volume 0 to 1.0
  cfg.delayVols[1]  = 0.0;     // delay chan volume 0 to 1.0
  cfg.recirculate   = 0.0;     // delay Recirculate aka feedback level 0 to 1.0

  // flanger
  cfg.flangerSpeed    = 1.6;   // effects rate, Hz
  cfg.flangerDepth    = 128;   // effect 'strength'

  // chorus effect
  cfg.chorusVoices    = 2;
  cfg.chorusVolume    = 0.5;

  // input level
  cfg.inputLevel      = 5;     // 0 to 15, 5 = 1.33vpp

  // general
  cfg.lastMenu        = 0;
}



bool loadConfig()
{
  byte version;

  // init eeprom library
  EEPROM.begin();
  delay(100);

  // load default settings
  loadDefaults();

  // check version of stored config
  EEPROM.get(EEPROM_ADDR, version);
  Serial.print("EEPROM Stored Version   = "); Serial.println(version);
  Serial.print("EEPROM Required Version = "); Serial.println(EEPROM_VERSION);

  if (version == EEPROM_VERSION)
  {
    EEPROM.get(EEPROM_ADDR, cfg);
    delay(200);
    Serial.println("Stored Config loaded");
    Serial.print("loaded "); Serial.print(sizeof(cfg)); Serial.println(" bytes");
    return true;
  }
  else
  {
    Serial.println("Config NOT loaded, using defaults");
    //clearEEPROM();
  }

  return false;
}



bool saveConfig()
{
  // don't store if version is 0, used for dev to force defaults
  if (EEPROM_VERSION == 0)
    return false;

  cfg.vers = EEPROM_VERSION;
  EEPROM.put(EEPROM_ADDR, cfg);
  Serial.print("Saved "); Serial.print(sizeof(cfg)); Serial.println(" bytes");
  return true;
}





// clear eeprom contents (dev use only so far)
void clearEEPROM()
{
  Serial.println("Clearing EEPROM...");

  for (int i = 0 ; i < EEPROM.length() ; i++)
    EEPROM.write(i, 0xFF);

  Serial.println("done");
}



// show eeprom contents (dev use only so far)
void showEEPROM()
{
  byte b;

  Serial.println("EEPROM contents:");

  for (int i = 0 ; i < EEPROM.length() ; i++)
  {
    EEPROM.get(i, b);

    Serial.print("Addr 0x");
    Serial.print(i, HEX);
    Serial.print(" = ");
    Serial.println(b);
  }

  Serial.println();
}

#endif

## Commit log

2020-01-15 Major cleanup, bug fixes
    Holding down tuner button sets a dev mode that allows changes to behavior without affecting normal operation. Use to enable test tone using wahwah button. Enabled headphones output in addion to line out, need provision to adjust level. Added line out level indicator in input screen. Added 4 channel delay and screen. Added detection of a long press on effects buttons to allow toggling of 8 effects, no led indicators though. Selecting an effect also switches screens to the effect chosen. Reverb is now downstream of the other effects, which required a new mixer and logic changes. Guitar tuner fixes, seems to be working pretty good when compared to a commercial product.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
    [Compressor.h, Flanger.h, config.h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]
2022-07-25 Added hardware files
    General cleanup
    [GEP Analog Board V100.brd, GEP Analog Board V100.sch, GEP Main Board V1.0.brd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]

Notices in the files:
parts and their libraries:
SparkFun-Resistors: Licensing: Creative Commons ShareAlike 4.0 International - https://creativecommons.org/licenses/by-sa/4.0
